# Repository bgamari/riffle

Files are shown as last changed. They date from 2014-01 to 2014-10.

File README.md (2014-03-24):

# riffle sensor hardware

This repository contains the hardware designs for the Riffle open-source
water-quality sensor. The sensor consists of two distinct pieces of hardware:
the remote board and the logic board.

## logic board

The logic board contains,
  
  * a step-down voltage regulator
  * A Freescale MK20DX128 microcontroller
  * an SPI FLASH device
  * an SD card slot
  * A ten-pin IDC connector for interfacing with the remote board
  * A connector for an NRF24L01 radio
  * Various other connectors

The MCU runs the [data-logger firmware](http://www.github.com/bgamari/data-logger).
Schematics can be found in the
[fab branch](https://github.com/bgamari/water-quality/raw/fab/hardware/schematics.pdf).

## remote board

The remote board contains the sensors which line-of-sight to the medium being
measured. This includes,

  * A TMP100 temperature sensor
  * A MS5803 pressure sensor
  * A color sensor
  * Several LEDs and a GPIO extender to drive them
  * Logic for sensing electrical conductivity

All of these save the electrical conductivity sensor communicate with the logic
board over I2C.
Schematics can be found in the
[fab branch](https://github.com/bgamari/water-quality/raw/fab/remote-board/schematics.pdf).

## contributors

 * Laura Dietz (board layout)
 * Ben Gamari (schematics and board layout)
 * Don Blair (hardware design ideas)
 * Joshua Shapiro (helpful discussions regarding conductivity measurement)
 * Mark Green (helpful design feedback)

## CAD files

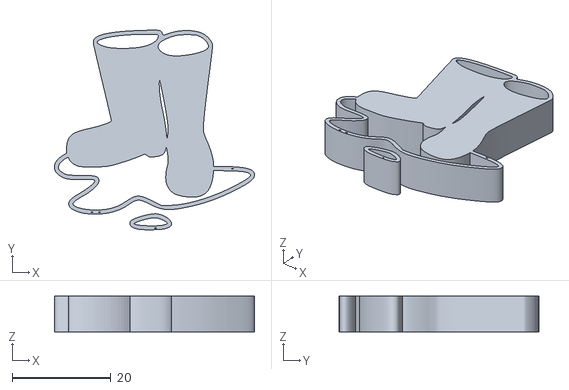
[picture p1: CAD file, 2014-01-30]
enclosure/boots-puddle.stl
40.5 x 40.5 x 7.21

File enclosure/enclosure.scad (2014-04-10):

// units
inch = 25.4;
mil = 1e-3 * inch;

with_logo = true;

// common dimensions
body_od = 54;
body_height = 32;

// square
square_width = 25.4;
square_height = 20.0;

// sensor board parameters
sensor_buffer = 6;
sensor_board_depth = 12; // radial dimension
sensor_board_width = 25;
sensor_board_height = 20 + 2; // axial dimension
sensor_board_rim_depth = 2; // radial

ec_electrode_spacing = 10;

// cable passage
passage_width = 16;
passage_height = 3.2;

// eye
eye_diam = 10;

// screw parameters
m3_screw_diam = 3.3;
m3_head_diam = 6.0;

delta = 0.01;

module tube(r_outer, thickness, h) {
    assign($fn=8)
    difference() {
        cylinder(r=r_outer, h=h);
        translate([0, 0, -1])
        cylinder(r=r_outer-thickness, h=h+2);
    }
}

module cap() {
    difference() {
        union() {
            // body
            cylinder(r=body_od/2, h=body_height, $fn=$fn*3);

            // Top square
            translate([0, 0, body_height + square_height/2 - delta])
            cube([square_width, square_width, square_height], center=true);

            // Logo
            if (with_logo)
            color("SteelBlue")
            rotate([0,0,90])
            translate([0, 0, body_height + square_height - 0.1])
            scale([0.5, 0.5, 0.3])
            import(file="boots-puddle.stl");

            // rim around sensor board recess
            translate([0.4*body_od, 0, sensor_buffer + sensor_board_height/2])
            scale([0.80, 1, 1])
            rotate([90,0,0])
            cylinder(r=0.6*sensor_board_height, h=sensor_board_width+3, center=true, $fn=40);
        }

        // flatten rim
        translate([body_od/2 + 10/2, 0, sensor_board_height/2 + sensor_buffer])
        cube([10, 2*sensor_board_width, 2*sensor_board_height], center=true);

        // board recess
        translate([body_od/2 - sensor_board_depth, 0, sensor_buffer])
        translate([0, -sensor_board_width/2, 0])
        cube([sensor_board_depth + sensor_board_rim_depth, sensor_board_width, sensor_board_height]);

        // Recess for wrench square
        cube([square_width, square_width, 2*square_height], center=true);

        // Cable passage
        translate([0, 0, sensor_buffer + passage_height/2])
        rotate([0, 90, 0])
        scale([1, passage_width/passage_height, 1])
        cylinder(r=passage_height/2, h=body_od);
         
        // EC electrodes
        for (y=[+1, -1])
        translate([0.35*body_od, y*ec_electrode_spacing/2, body_height])
        cylinder(r=3.3/2, h=body_height/2, center=true);

        // Eye
        rotate([0,0,90])
        translate([0, 0, body_height + square_height/2 + 0.6*square_width])
        rotate([90, 0, 0])
        rotate_extrude()
        translate([0.6*square_width, 0, 0])
        circle(r=eye_diam/2);

        // Screw holes
        for (theta = [-90, +90])
        rotate(theta)
        translate([square_width/2 + 4, 0, -1]) {
            cylinder(r=m3_screw_diam/2, h=50);
            translate([0, 0, 8+1])
            cylinder(r=m3_head_diam/2, h=50);
        }
   }
}

module cap_with_support() {
    n_supports = 3;

    cap($fn=20);

    // support for board recess
    for (theta = [0, 10, -10, 20, -20])
    rotate([0, 0, theta])
    translate([body_od / 2 - 1, 0, sensor_buffer])
    tube(1, 0.3, sensor_board_height);

    // support for top of square
    for (x = [0:n_supports])
    for (y = [0:n_supports])
    translate([square_width / (n_supports+1) * (x - n_supports/2),
               square_width / (n_supports+1) * (y - n_supports/2),
               0])
    tube(2.5, 0.3, square_height);
}

module pouring_jig() {
    wall = 0.35*7;
    height = 26;
    difference() {
        cube([height, wall*2+sensor_board_width, wall*2+sensor_board_height], center=true);

        translate([height,0,-sensor_board_height])
        cylinder(r=body_od/2, h=2*sensor_board_height, $fn=60);

        cube([2*height, sensor_board_width, sensor_board_height], center=true);
    }
}

cap_with_support();

/*
rotate([0, 90, 0])
translate([50,0,0])
translate([0, 0, sensor_board_height/2 + sensor_buffer])
rotate(180)
pouring_jig();
*/

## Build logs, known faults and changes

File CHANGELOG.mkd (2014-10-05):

# Hardware revisions

## v1

 * Logic board shield on MCHCK, sensor board
 * Several connectors

## v2

 * Combined connectors into single 10-pin IDC connector
 * Merged MCHCK onto logic board

## v2.1

 * Fixed various board issues
 * Switch to TMP100 temperature sensor

## v3

 * Added accelerometer (MMA8451Q) onto logic board

## v3.1

 * Simplified EC measurement to use GPIO pins and comparator

## v4.0

 * Merged remote board and logic board
 * Removed sensor voltage supply switching
 * Removed pressure sensor

## v4.1 (never produced)

 * Added BMP180 pressure sensor

## v4.2

 * A few pinning changes, shuffled traces around to preserve ground plane
 * Manufacturability improvements
 * Lowered I2C pull-up resistor values

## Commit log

2014-01-09 Add hardware
    [conductivity.sch, water-quality.sch]
2014-01-10 Beginnings of design
    [conductivity.sch, pressure.sch, water-quality.sch]
2014-01-10 Pretty much done?
    [conductivity.sch, pressure.sch, water-quality.sch]
2014-01-10 Clean up layout
    [conductivity.sch]
2014-01-10 Add some values
    [conductivity.sch]
2014-01-10 Add another missing value
    [pressure.sch]
2014-01-10 Capacitively couple EC probe
    [conductivity.sch]
2014-01-10 Use DISC output of 555 for MCU input
    [conductivity.sch]
2014-01-10 Add missing connection
    [water-quality.sch]
2014-01-10 Set 0603 footprints
    [conductivity.sch, pressure.sch]
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2014-01-10 Hide footprint attributes
    [pressure.sch]
2014-01-10 Fix divider values
    [pressure.sch]
2014-01-10 Bump up filter capacitor
    [pressure.sch]
2014-01-10 Clarify comment
    [conductivity.sch]
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2014-01-10 Rework pinning
    [water-quality.sch]
2014-01-10 Add external wakeup header
    [water-quality.sch]
2014-01-10 Fix labels
    [water-quality.sch]
2014-01-11 Move to new pressure sensor
    [conductivity.sch, pressure.sch, water-quality.sch]
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2014-01-11 Add MIC5205 footprint
    [conductivity.sch]
2014-01-11 Add 555 footprint
    [conductivity.sch]
2014-01-11 Fix net names
    [water-quality.sch]
2014-01-11 Another stab at artwork, this time with proper handedness
    [conductivity.sch, water-quality.sch]
2014-01-11 Clean things up
    [water-quality.sch]
2014-01-11 Fix debug connector
    [water-quality.sch]
2014-01-11 Add more bypassing
    [conductivity.sch, water-quality.sch]
2014-01-11 More bypassing
    [water-quality.sch]
2014-01-13 Add flow sensor
    [water-quality.sch]
2014-01-14 Fix chip select lines
    [water-quality.sch]
2014-01-15 Add turbidity sensing
    [water-quality.sch]
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2014-01-15 Add second LED for turbidity/chlorophyll characterization
    [water-quality.sch]
2014-01-15 Add transimpedance amplifier for photodiode
    [turbidity.sch, water-quality.sch]
2014-01-19 Place turbidity resistors on low-side
    [turbidity.sch]
2014-01-19 Add remote board
    [remote-board.sch]
2014-01-19 Finish remote board
    [remote-board.sch]
2014-01-19 Another revision of remote board
    [remote-board.sch]
2014-01-19 Fold LM19 connector into I2C connector
    [conductivity.sch, water-quality.sch]
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2014-01-19 remote-board: Change connector name
    [remote-board.sch]
2014-01-19 Move photodiode amplifier onto remote board
    [remote-board.sch, turbidity.sch]
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2014-01-20 enclosure: Move eye into separate module
    [enclosure.scad]
2014-01-20 Move eye to separate piece
    [enclosure.scad]
2014-01-20 Fix Z alignment
    [enclosure.scad]
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2014-01-20 enclosure: Eliminate need for support
    [enclosure.scad]
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2014-01-20 Add support for board recess
    [enclosure.scad]
2014-01-20 Bump up M3 head diameter
    [enclosure.scad]
2014-01-20 Center EC wires over board
    [enclosure.scad]
2014-01-20 Fix sensor_board_height
    [enclosure.scad]
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2014-01-21 Fix too-small middle_diam
    [enclosure.scad]
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2014-01-29 Rework enclosure
    [enclosure.scad]
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2014-01-30 Add logo to top of cap
    Traced bitmap and fixed up polygons with inkscape. Extruded with
    Blender.
    [boots-puddle.stl, enclosure.scad]
2014-02-04 Initial design rework
    [water-quality.sch]
2014-02-04 More reworking
    [conductivity.sch, turbidity.sch, water-quality.sch]
2014-02-04 Move TLC555 onto remote board
    [conductivity.sch, remote-board.sch, water-quality.sch]
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2014-02-08 Add SCLK net name
    [water-quality.sch]
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2014-02-08 Fix more rails
    [water-quality.sch]
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2014-02-08 Fix FLASH CS net name
    [water-quality.sch]
2014-02-08 Fix MOSFETs
    [water-quality.sch]
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2014-02-08 near final board layout
    [water-quality.sch]
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2014-02-09 remote: Add another LED and fix up DRC
    [remote-board.sch]
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2014-02-09 Add reed switch to remote board
    [remote-board.sch]
2014-02-09 Make remote board pinning consistent with logic board
    [remote-board.sch, water-quality.sch]
2014-02-10 Support powering from USB
    [water-quality.sch]
2014-02-10 Route missing EC_OUT net
    [water-quality.sch]
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2014-02-11 Fix pin ordering
    [water-quality.sch]
2014-02-11 Fix remote connector pinning
    [remote-board.sch, water-quality.sch]
2014-02-12 Add +3.3V pin to UART connector
    [water-quality.sch]
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2014-02-13 Add bypassing for SD card
    [water-quality.sch]
2014-02-13 Ground unused remote bus pin
    [remote-board.sch, water-quality.sch]
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2014-02-25 Add L3 for step-down converter
    [water-quality.sch]
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2014-02-25 Fix USB connector mask clearance
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2014-02-28 Switch to TMP100 for temperature sensing
    [remote-board.sch]
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2014-03-02 Revert "remote-board: Make ribbon cable footprint smaller"
    This reverts commit d1e1506afd45d06d9e3468316f10c71e78c81df6. It's
    already pretty small.
    Conflicts:
    remote-board/remote-board.pcb
2014-03-02 remote-board: Fix pin marking
2014-03-02 enclosure: Shrink things a bit (WIP)
    [enclosure.scad]
2014-03-03 remote-board; Fix up silk
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2014-03-04 Fix DM3AT footprint
2014-03-05 Really fix microSD slot this time
2014-03-05 Add SD card detect
    [water-quality.sch]
2014-03-05 Fix SD card model
    [water-quality.sch]
2014-03-05 Fix MOSFET polarities
    [water-quality.sch]
2014-03-07 enclosure: Add screw holes
    [enclosure.scad]
2014-03-07 Fix screw parameters
    [enclosure.scad]
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2014-03-17 enclosure: Fix pouring jig wall thickness
    [enclosure.scad]
2014-03-17 remote-board: Fix TMP100 pinning
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2014-03-17 Fix pouring jig height
    [enclosure.scad]
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2014-03-23 enclosure: Tweak screw dimensions and support
    [enclosure.scad]
2014-03-23 logic board: Fix SD card orientation
    [water-quality.sch]
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2014-03-23 v3.0: Add ADXL345 accelerometer
    [water-quality.sch]
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2014-03-23 v3.1: Use GPIO-based EC measurement
    [remote-board.sch, water-quality.sch]
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2014-03-24 Add missing EC_OUT net
    [remote-board.sch, water-quality.sch]
2014-03-24 logic board: Use comparator for EC sensing
    [water-quality.sch]
2014-03-25 Clarify "board issues"
2014-03-28 Add +5V power connector and switch
    [water-quality.sch]
2014-03-31 logic board: Spread out components and fix DRC issues
2014-03-31 enclosure: Expand cable passage
    [enclosure.scad]
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2014-04-10 enclosure: New electrode configuration
    [enclosure.scad]
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2014-04-10 remote-board: Add missing elements
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2014-04-11 remote-board: Only need one conductivity excitation pin
    [remote-board.sch]
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2014-04-11 fixed ec probes sort of
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2014-04-16 Add resistor to stabilize buffer
    [remote-board.sch]
2014-04-16 Move current limiting resistor
    [remote-board.sch]
2014-04-16 Add missing trace and fix up silk
    [remote-board.sch]
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2014-04-16 Add potential for gain on output amplifier
    [remote-board.sch]
2014-04-18 Add pull-down for floating EC net
    [remote-board.sch]
2014-04-18 Switch to cheaper accelerometer
    [water-quality.sch]
2014-04-18 Add I2C addresses to schematic
    [water-quality.sch]
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2014-04-18 remote-board: Add pull-down resistor footprint
    [remote-board.sch]
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2014-04-18 Add TMP100 to logic board for giggles
    [water-quality.sch]
2014-04-18 Give resistors more clearance
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2014-09-16 Beginning of simplified v4
    [water-quality.sch]
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2014-09-16 Read tmp10x and add GPIO to header
    [water-quality.sch]
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2014-09-16 Add reed switch and clean up
    [water-quality.sch]
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2014-09-16 Bring out another GPIO pin
    [water-quality.sch]
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2014-10-04 Bump down I2C pull-up values
    [water-quality.sch]
2014-10-04 Fix TMP100 I2C address
    [water-quality.sch]
2014-10-04 Clarify power supply options
    [water-quality.sch]
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2014-10-05 Shuffling traces and some pinning changes
    [water-quality.sch]
2014-10-05 Fix BMP180 address
    [water-quality.sch]
